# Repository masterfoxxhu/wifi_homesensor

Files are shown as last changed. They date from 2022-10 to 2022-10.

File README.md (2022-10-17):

# wifi_homesensor
Quick and dirty ESP8266 based thermo and humidity meter for ESPhome

Based around a Wemos D1 mini module, using SHT31 sensor, and a MCP16301 DCDC converter.\
Enclosure [PA62W](https://lomex.hu/hu/webshop/%23/search,47-02-16/stype,1)

A  render of the board.\
The sensor is located on the bottom of the board to minimise heat pickup from the rest of the board. There is a vent near the sensor on the enclosure.

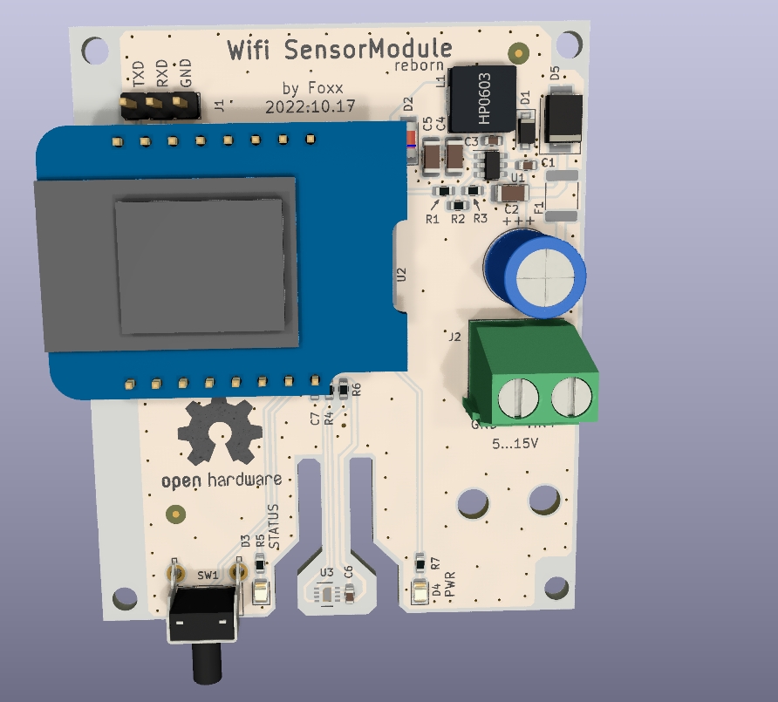
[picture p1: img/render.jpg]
render from kicad


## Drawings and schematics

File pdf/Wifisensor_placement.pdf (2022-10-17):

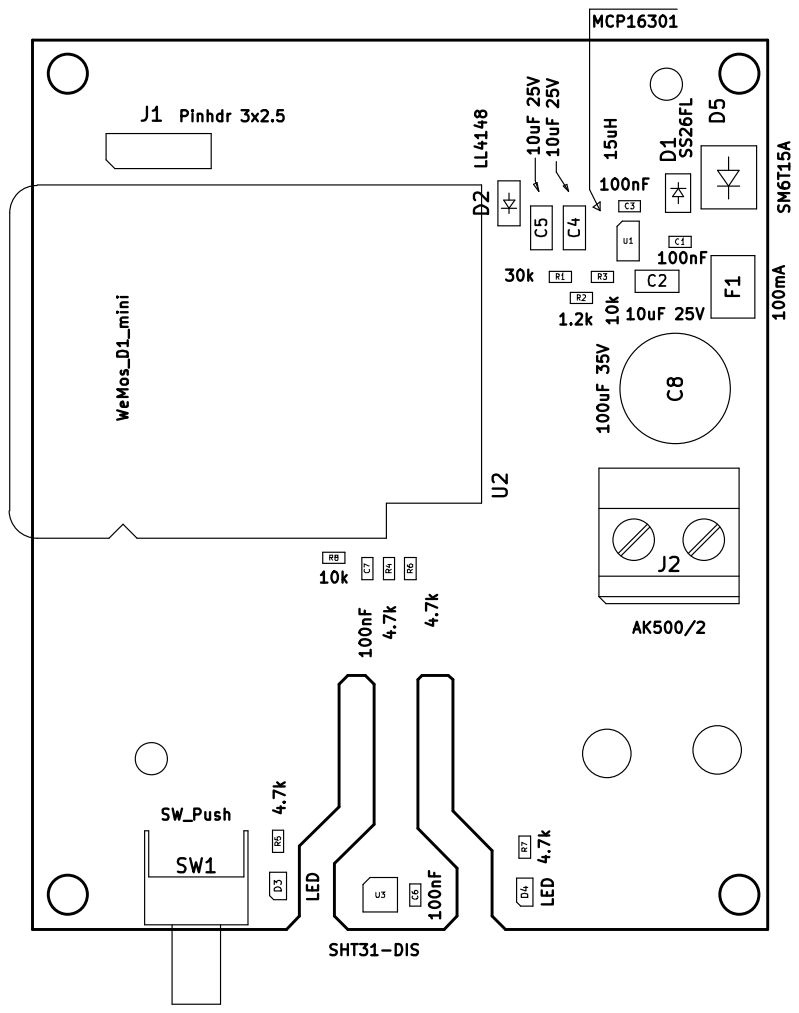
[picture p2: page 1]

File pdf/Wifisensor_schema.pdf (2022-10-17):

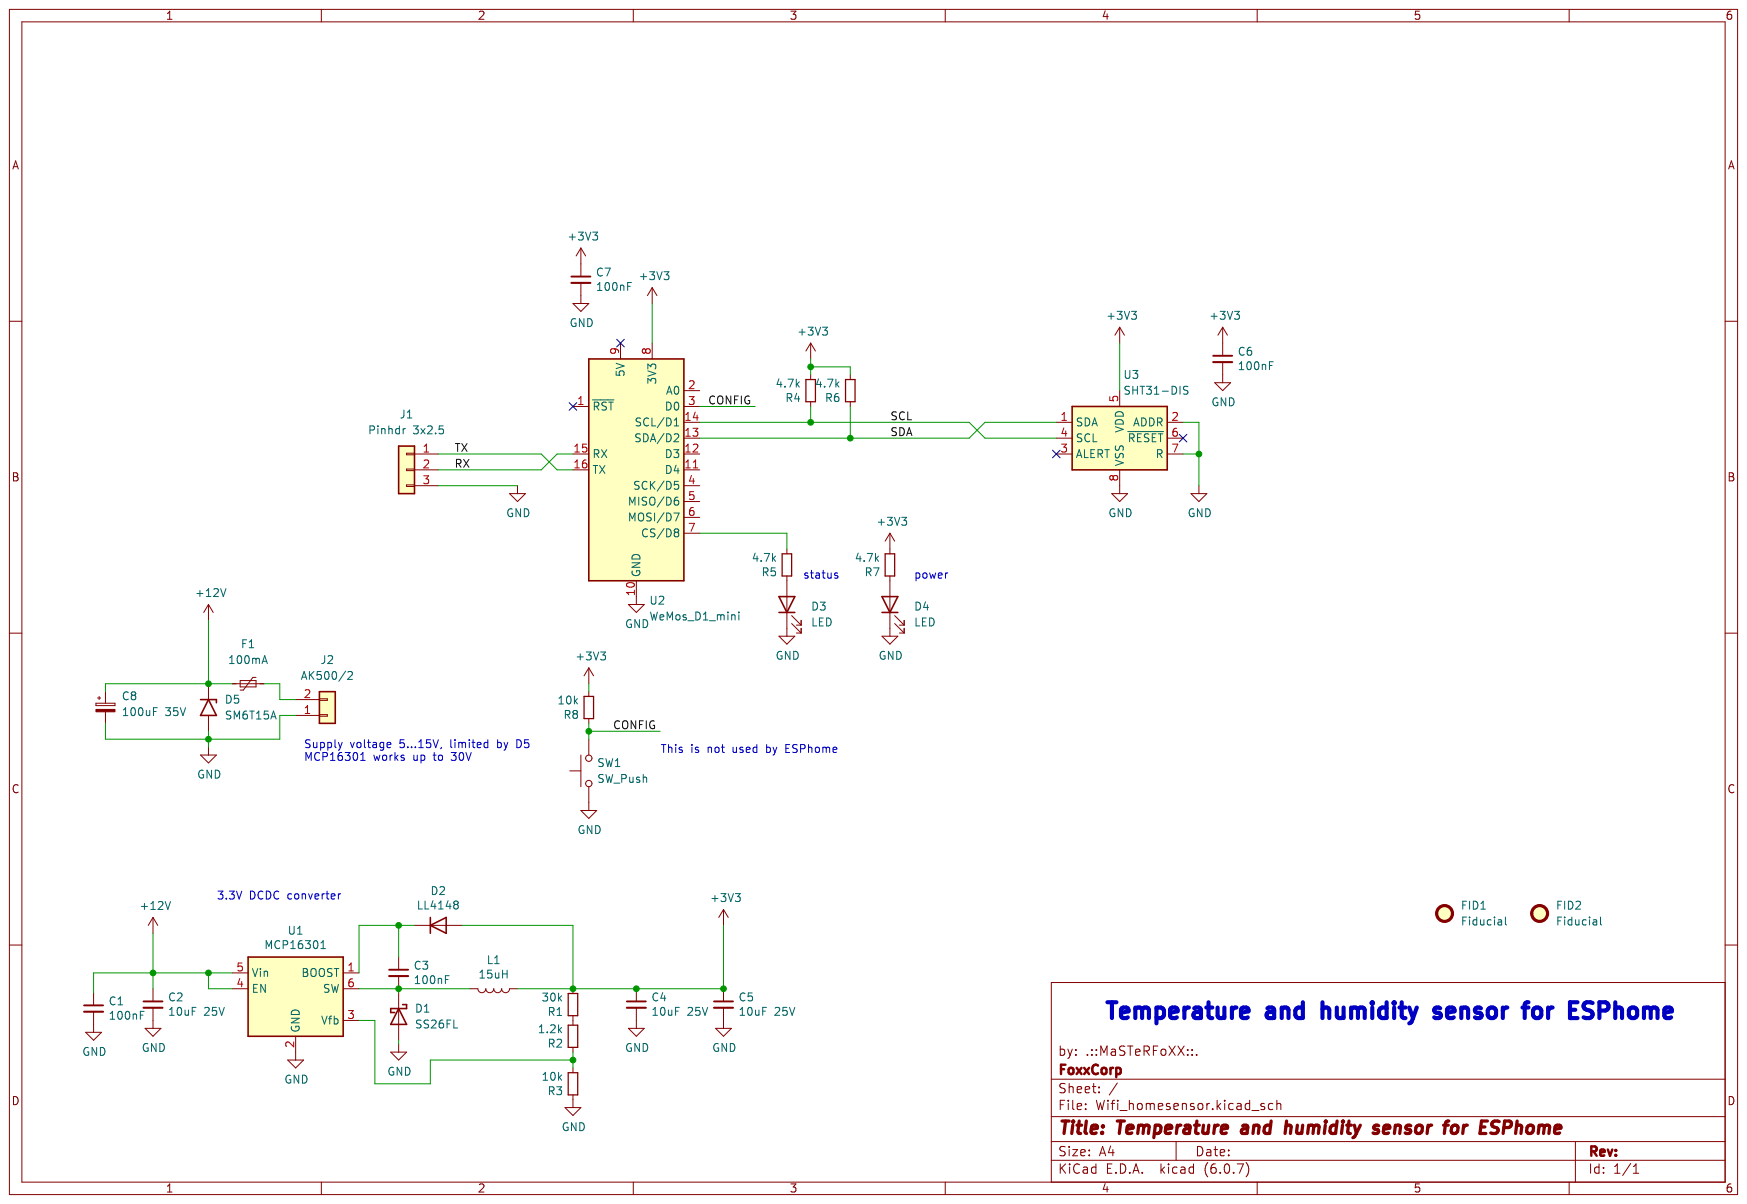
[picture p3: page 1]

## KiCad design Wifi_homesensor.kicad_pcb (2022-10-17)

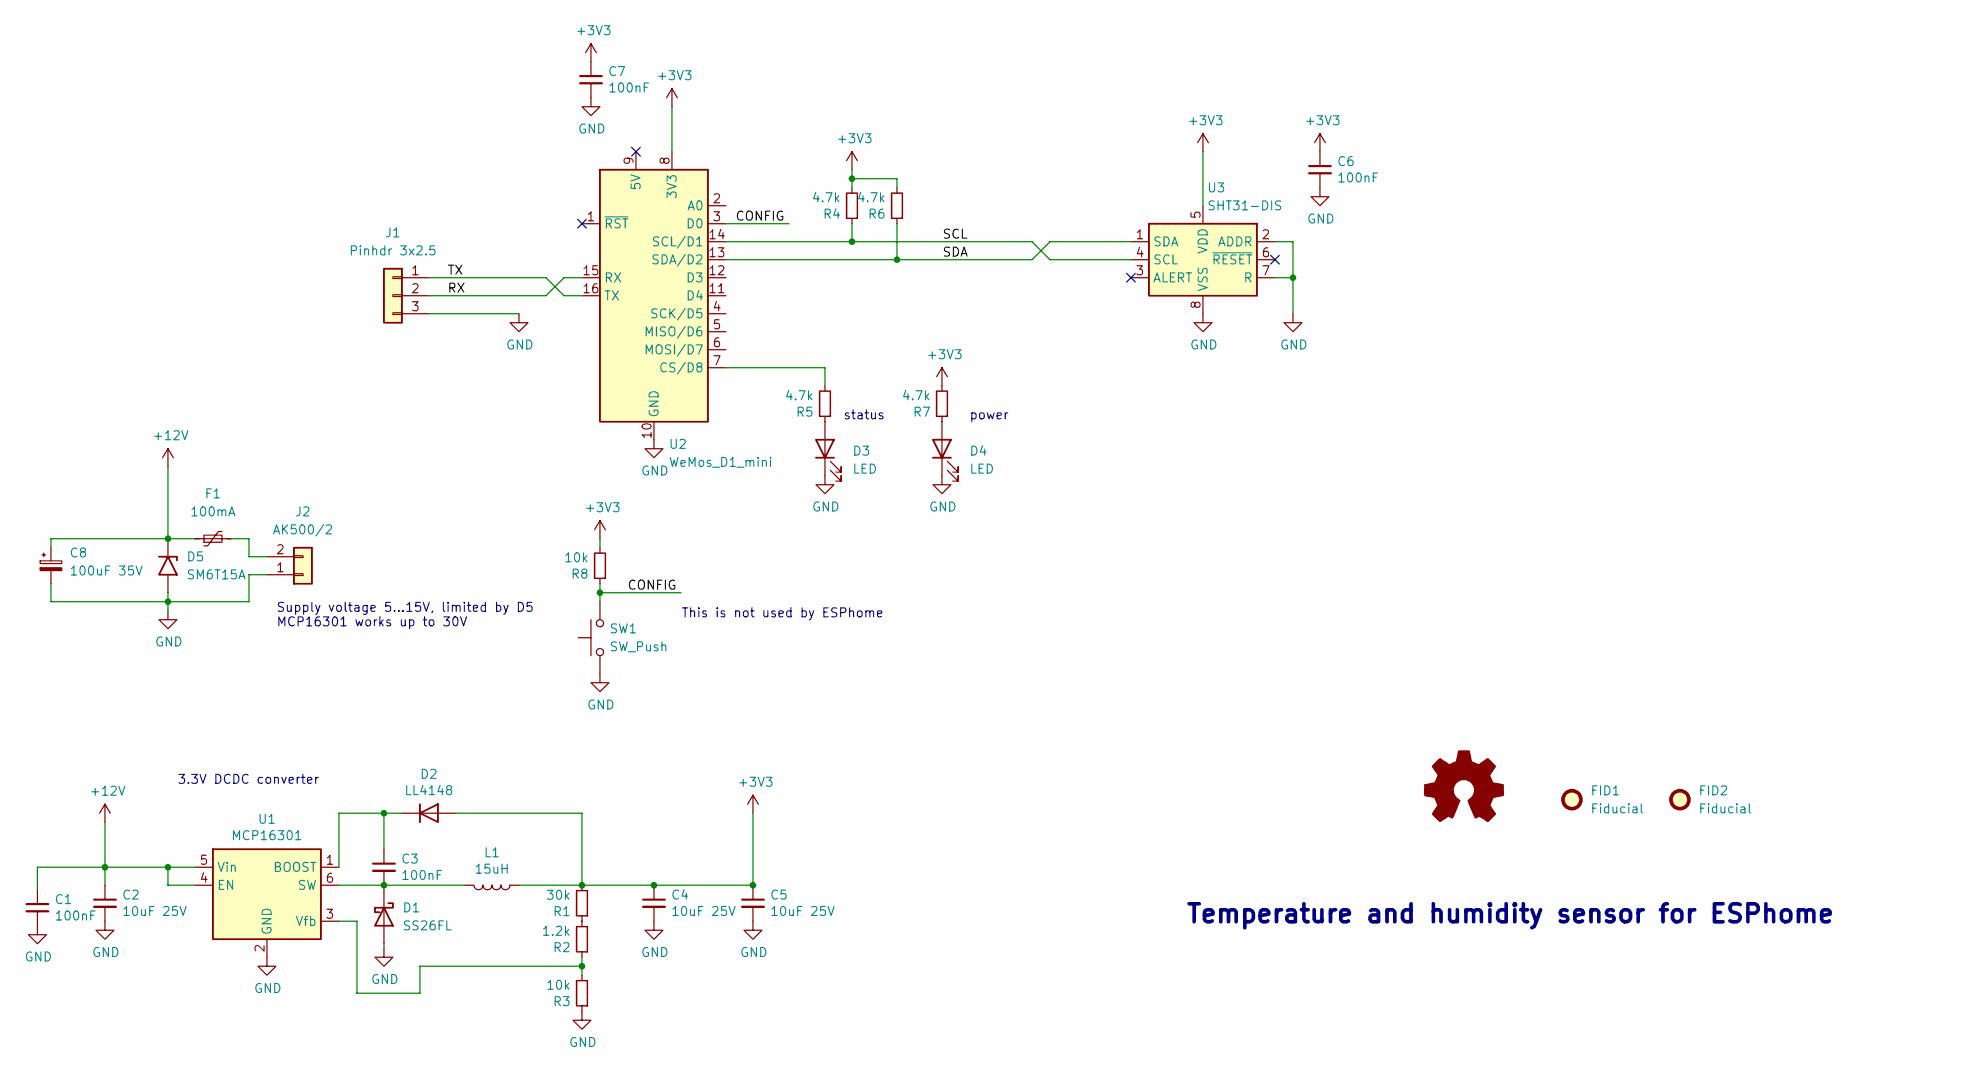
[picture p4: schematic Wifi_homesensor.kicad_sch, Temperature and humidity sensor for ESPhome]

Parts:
C1, C3, C6, C7: 100nF; C_0603_1608Metric
C2, C4, C5: 10uF 25V; C_1206_3216Metric
C8: 100uF 35V; C_Radial_D8.0mm_H11.5mm_P3.50mm
D1: SS26FL; D_SOD-123F
D2: LL4148; D_MiniMELF
D3, D4: LED; LED_0805_2012Metric
D5: SM6T15A; D_SMB
F1: 100mA; Fuse_1812_4532Metric
FID1, FID2: Fiducial; Fiducial_0.75mm_Mask2.25mm
J1: Pinhdr 3x2.5; PinHeader_1x03_P2.54mm_Vertical
J2: AK500/2; TerminalBlock_Phoenix_MKDS-1,5-2-5.08_1x02_P5.08mm_Horizont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
L1: 15uH; inductor_6_5x6_5
LOGO1: Logo_Open_Hardware_Small; OSHW-Logo2_14.6x12mm_SilkScreen
R1: 30k; R_0603_1608Metric
R2: 1.2k; R_0603_1608Metric
R3, R8: 10k; R_0603_1608Metric
R4, R5, R6, R7: 4.7k; R_0603_1608Metric
SW1: SW_Push; SW_Tactile_SPST_Angled_PTS645Vx83-2LFS
U1: MCP16301; SOT-23-6
U2: WeMos_D1_mini; WEMOS_D1_mini_light
U3: SHT31-DIS; Sensirion_DFN-8-1EP_2.5x2.5mm_P0.5mm_EP1.1x1.7mm

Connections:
+3V3: C4.1, C5.1, C6.1, C7.1, D2.2 (A), L1.1, R1.2, R4.2, R6.2, R7.2, R8.2, U2.8 (3V3), U3.5 (VDD)
+12V: C1.1, C2.1, C8.1, D5.1 (A1), F1.1, U1.4 (EN), U1.5 (Vin)
/CONFIG: R8.1, SW1.2, U2.3 (D0)
/RX: J1.2, U2.15 (RX)
/SCL: R4.1, U2.14 (SCL/D1), U3.4 (SCL)
/SDA: R6.1, U2.13 (SDA/D2), U3.1 (SDA)
/TX: J1.1, U2.16 (TX)
GND: C1.2, C2.2, C4.2, C5.2, C6.2, C7.2, C8.2, D1.2 (A), D3.1 (K), D4.1 (K), D5.2 (A2), J1.3, J2.1, R3.1, SW1.1, U1.2 (GND), U2.10 (GND), U3.2 (ADDR), U3.7 (R), U3.8 (VSS), U3.9 (VSS)
unnamed: C3.1, D2.1 (K), U1.1 (BOOST)
unnamed: C3.2, D1.1 (K), L1.2, U1.6 (SW)
unnamed: D3.2 (A), R5.1
unnamed: D4.2 (A), R7.1
unnamed: F1.2, J2.2
unnamed: R1.1, R2.2
unnamed: R2.1, R3.2, U1.3 (Vfb)
unnamed: R5.2, U2.7 (CS/D8)

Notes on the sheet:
Temperature and humidity sensor for ESPhome
status
This is not used by ESPhome
3.3V DCDC converter
Supply voltage 5...15V, limited by D5 MCP16301 works up to 30V
power

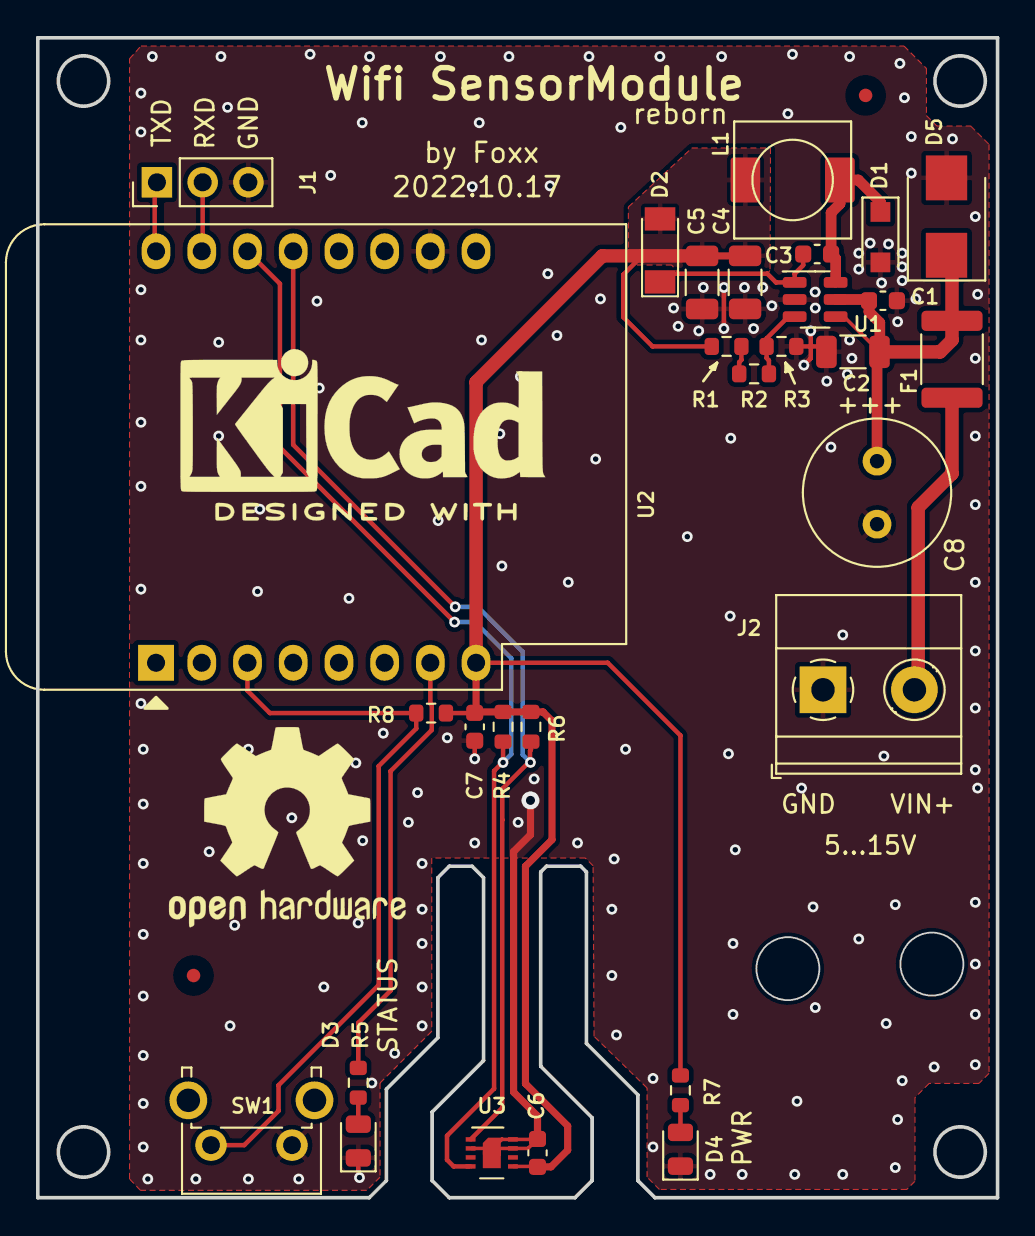
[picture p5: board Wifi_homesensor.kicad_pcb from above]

Board: 2 copper layers, 53.3 x 64.4 mm, 33 parts (0 on the bottom side), 16 nets.

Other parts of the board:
LOGO2: KiCad-Logo2_8mm_SilkScreen

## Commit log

2022-10-08 schematic almost finished
    [Wifi_homesensor.kicad_pcb, Wifi_homesensor.kicad_sch]
2022-10-15 schematic finished, pcb editing started
    [Wifi_homesensor.kicad_pcb, Wifi_homesensor.kicad_sch]
2022-10-17 pcb finished
    [Wifi_homesensor-B_Cu.gbr, Wifi_homesensor-B_Mask.gbr, Wifi_homesensor-B_Paste.gbr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]
